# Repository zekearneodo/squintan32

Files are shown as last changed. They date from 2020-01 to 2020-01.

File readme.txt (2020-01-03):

Design files and helpers for a modular microdrive and headstage.

Authors: Ezequiel Arneodo, Corinna Lorenz, Richard Hahnloser.

Documentation in progress.

Deliverables:

 - rhd_2132_with_squiggle_logic: headstage module with intan chip, squiggle drive and controller/hall sensor for position monitoring. 
				 Molex connector for the probe.
	TODO: ready, produced with swisspcb (electric), mounted with Hybrid S.A
		
	main files:
	 - rhd_board.PrjPcb (altium project)

 - rev_1_mechanic: mechanical designs that go together with rhd_2132_with_squiggle_logic.
	TODO: ready, negotiating production with and with eth physics workshop (mechanical).

	main files:
	 - drive_rev_1.SLDASM

 - probe: pcb for assembly of the carbon fiber bundle probe. Connects to rhd_2132_with_squiggle with molex connector.
 	TODO: ready, negotiating production with swisspcb (electric)
	
	main files:
	 - probe_rev1.PrjPcb

 - altium_libraries: libraries of components with relevant 3d models (for connectors/microdrive).

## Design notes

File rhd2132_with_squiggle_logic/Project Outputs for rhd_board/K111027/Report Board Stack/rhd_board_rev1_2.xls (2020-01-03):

Board Stack Report
Stack Up |  |  |  | Layer Stack
Layer | intan | omnet-intan | intan-drive | Name | Material | Thickness | Constant
1 |  |  |  | Top Paste
2 |  |  |  | Fotolack | Solder Resist |  | 3.5
3 |  |  |  | Top Layer | Copper | 0.012mm
4 |  |  |  | Dielectric 1 | FR-4 | 0.022mm | 4.2
5 |  |  |  | Adhesive 1 |  | 0.025mm | 4.2
6 |  |  |  | GND | Copper | 0.012mm
7 |  |  |  | Adhesive 2 |  | 0.025mm | 4.2
8 |  |  |  | Dielectric 2 | FR-4 | 0.022mm | 4.2
9 |  |  |  | Bottom layer | Copper | 0.012mm
10 |  |  |  | Bottom Solder | Solder Resist |  | 3.5
11 |  |  |  | Bottom Paste
 | Height : 0.130mm | Height : 0.118mm | Height : 0.106mm

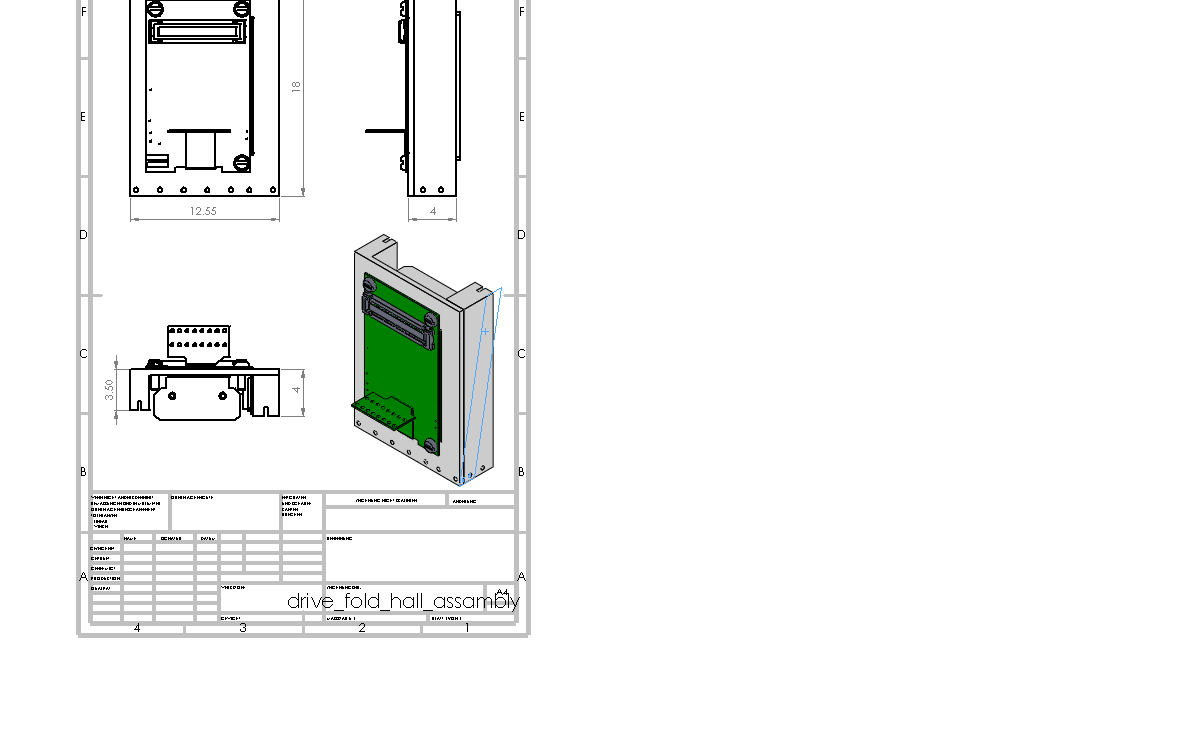
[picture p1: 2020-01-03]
rev_1_mechanic/drive_fold_hall_assambly.PNG

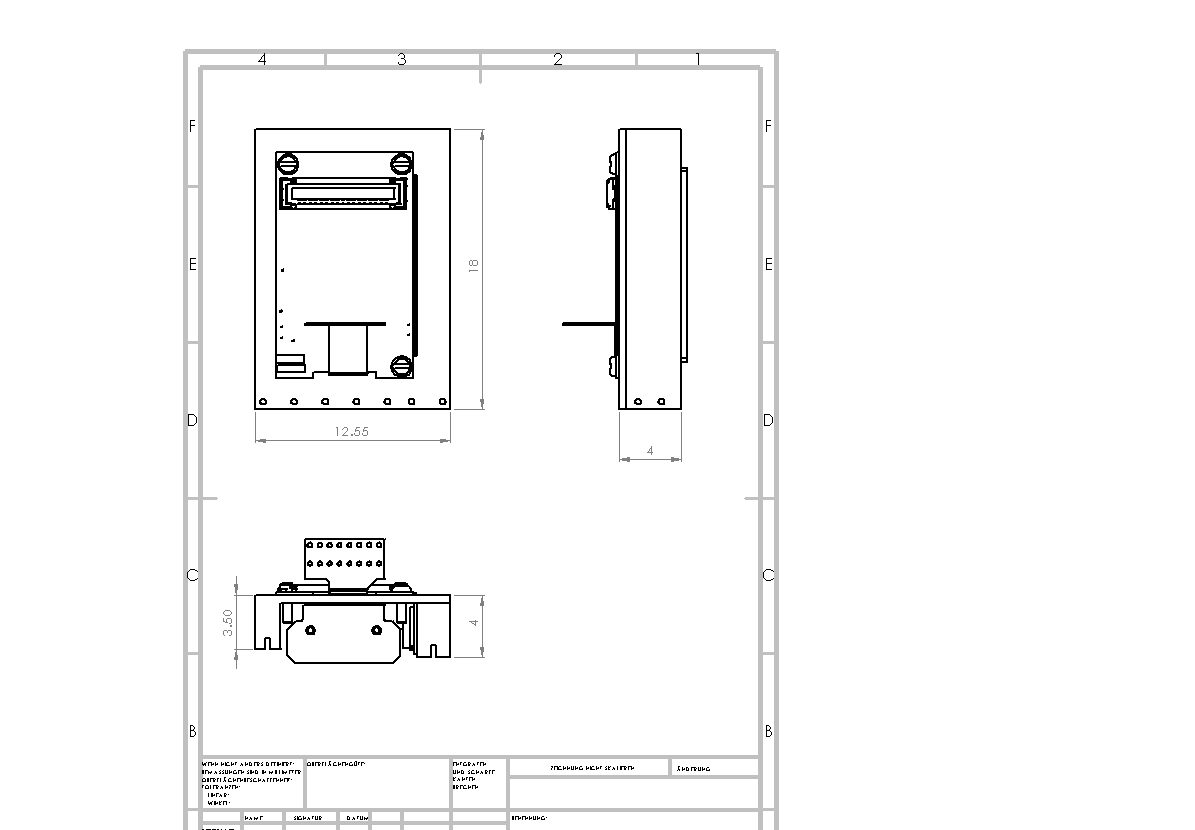
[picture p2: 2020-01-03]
rev_1_mechanic/drawings/drive_fold_hall_assambly.PNG

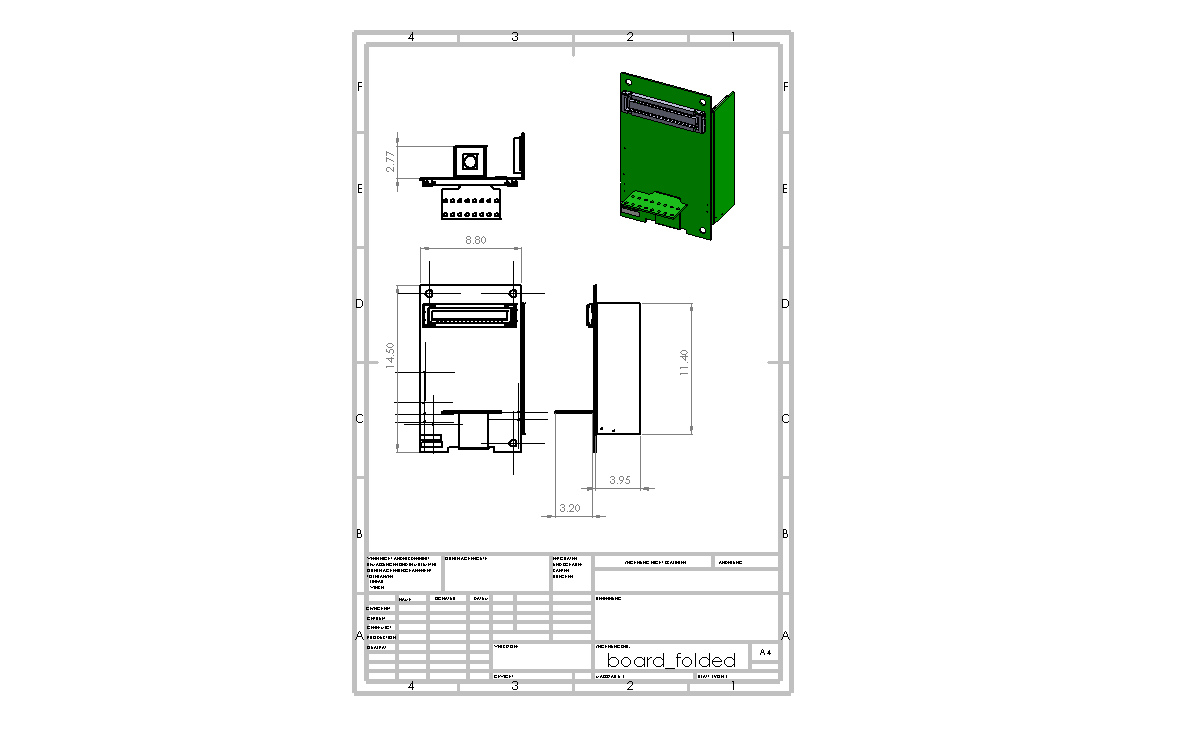
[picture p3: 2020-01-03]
rhd2132_with_squiggle_logic/output_3d_model/board_folded.PNG

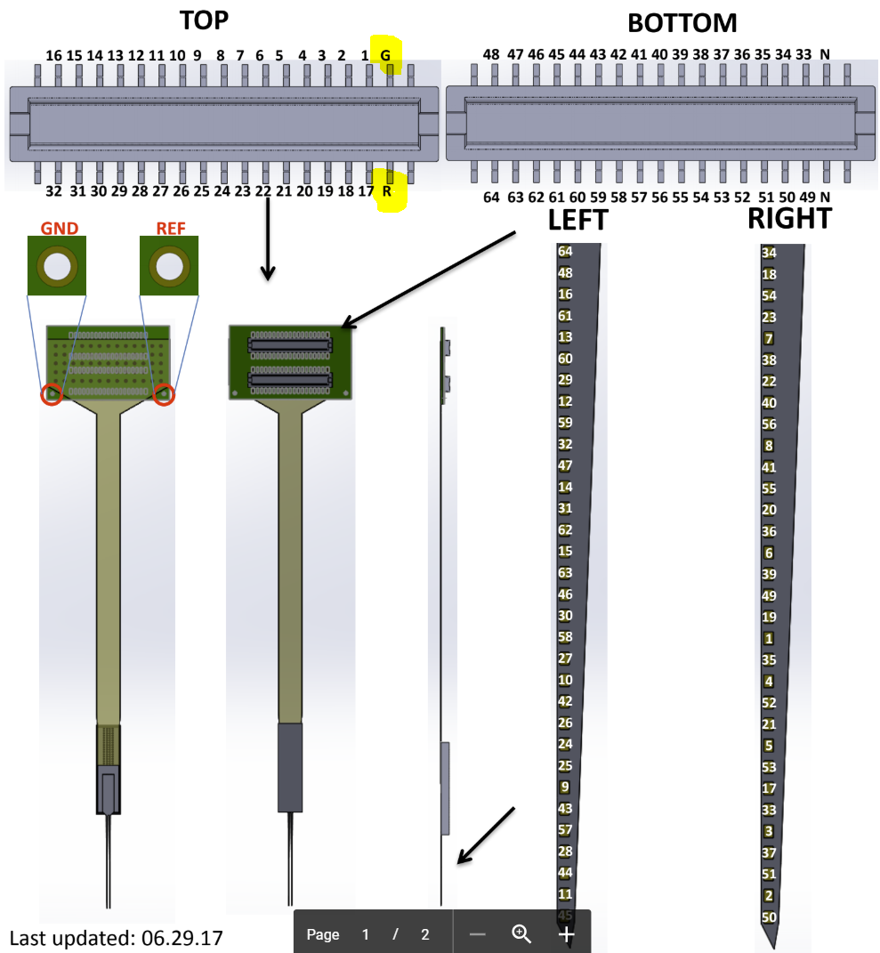
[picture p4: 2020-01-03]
datasheets/cambridge_neuro_64_map.png

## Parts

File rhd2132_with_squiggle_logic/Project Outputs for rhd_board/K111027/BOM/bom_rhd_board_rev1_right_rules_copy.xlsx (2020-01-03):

Comment | Description | Designator | Footprint | LibRef | Manufacturer 1 | Manufacturer Part Number 1 | Quantity | Supplier 1 | Supplier Part Number 1 | assembly comments
PCB Test Point |  | AI, AI2, AI3, DO, gnd-u, GND, REF, vcc-u, VDD | TESTPOINT_SMALL | TESTPOINT_SMALL |  |  | 9
100nF |  | C1 | 0402-SMALL | C_0402 | Taiyo Yuden (https://octopart-clicks.com/click/altium?sku=963-TMK063ABJ104KP-F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) | TMK063ABJ104KP-F (https://octopart-clicks.com/click/altium?sku=963-TMK063ABJ104KP-F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) | 1 | Mouser | 963-TMK063ABJ104KP-F (https://octopart-clicks.com/click/altium?sku=963-TMK063ABJ104KP-F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)
10nF |  | C2 | 0402-SMALL | C_0402 | Taiyo Yuden (https://octopart-clicks.com/click/altium?sku=963-TMK063BJ103KP-F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) | TMK063BJ103KP-F (https://octopart-clicks.com/click/altium?sku=963-TMK063BJ103KP-F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) | 1 | Mouser | 963-TMK063BJ103KP-F (https://octopart-clicks.com/click/altium?sku=963-TMK063BJ103KP-F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)
470n | Capacitor | C7, C9, C10 | CAPC0603X03L | Cap-0201 | Taiyo Yuden (https://octopart-clicks.com/click/altium?sku=963-AMK063BJ474MP-F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) | AMK063BJ474MP-F (https://octopart-clicks.com/click/altium?sku=963-AMK063BJ474MP-F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) | 3 | Mouser | 963-AMK063BJ474MP-F (https://octopart-clicks.com/click/altium?sku=963-AMK063BJ474MP-F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)
10u | Capacitor | C8, C11 | CAPC1608X09L | Cap-0603 | Panasonic (https://octopart-clicks.com/click/altium?sku=667-ECJ-1VB0J106M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) | ECJ-1VB0J106M (https://octopart-clicks.com/click/altium?sku=667-ECJ-1VB0J106M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) | 2 | Mouser | 667-ECJ-1VB0J106M (https://octopart-clicks.com/click/altium?sku=667-ECJ-1VB0J106M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)
NSD-2101 |  | D0 | BGA16C40P4X4_175X175X63 | NSD-2101 | austriamicrosystems | nsd-2101CSP | 1
NSE-5310_FC |  | D1 | NSE-5310_FC | NSE-5310_FC | austriamicrosystems | 179910002 | 1
sql-rv-1.8-6-12 | Squiggle motor | piezo-drive | sql-rv-1.8-6-12 | sql-rv-1.8-6-12 |  |  | 1 |  |  | will be assembled later in the lab
0 |  | R0 | 0201-SMALL | R_0402 | Panasonic (https://octopart-clicks.com/click/altium?sku=667-ERJ-1GN0R00C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) | ERJ-1GN0R00C (https://octopart-clicks.com/click/altium?sku=667-ERJ-1GN0R00C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) | 1 | Mouser | 667-ERJ-1GN0R00C (https://octopart-clicks.com/click/altium?sku=667-ERJ-1GN0R00C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)
100 |  | R1, R2, R3 | 0201-SMALL | R_0402 | Rohm (https://octopart-clicks.com/click/altium?sku=755-UCR006YVPFLR100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) | UCR006YVPFLR100 (https://octopart-clicks.com/click/altium?sku=755-UCR006YVPFLR100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) | 3 | Mouser | 755-UCR006YVPFLR100 (https://octopart-clicks.com/click/altium?sku=755-UCR006YVPFLR100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)
Omnetics_PZN-16-DD |  | S0 | OMNETICS_PZN-16-DD | Omnetics_PZN-16-DD |  |  | 1 |  |  | will be assembled later in the lab
Molex 3.5mm Pitch Slimstack 34 pin connector |  | S1 | MOLEX_504618-3412 | MOLEX_504618-3412 | Molex (https://octopart-clicks.com/click/altium?sku=538-504618-3410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) | 5046183410 (https://octopart-clicks.com/click/altium?sku=538-504618-3410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) | 1 | Mouser | 538-504618-3410 (https://octopart-clicks.com/click/altium?sku=538-504618-3410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)
Intan Technologies RHD2132 chip |  | U0 | RHD2000_56PIN_COB | RHD2132_COB | Intan Technologies | #P8004 | 1 |  |  | COB assembly

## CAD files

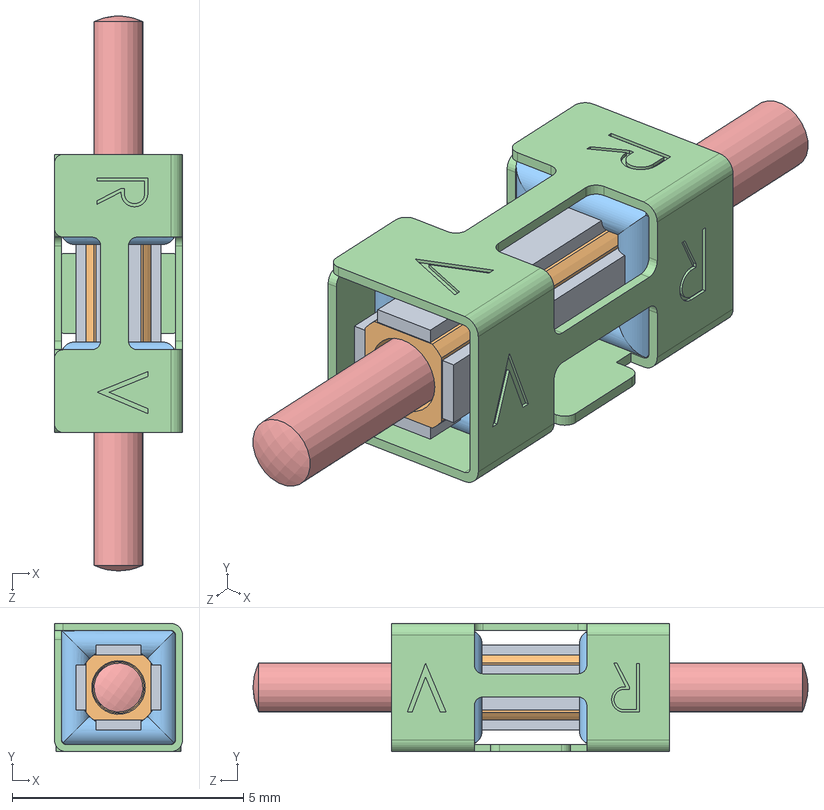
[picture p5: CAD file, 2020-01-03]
altium_libraries/Microdrive_Drive/3d_footprints/SQL-RV-1.8-6-12_nocable.STEP.SLDASM
2.77 x 2.77 x 12.0 mm
01594-0-0000_drawing view
02559-0-0000_WRAPPED x 2
02915-0-0000_Correct Wrap
01593-0-1012_MODEL

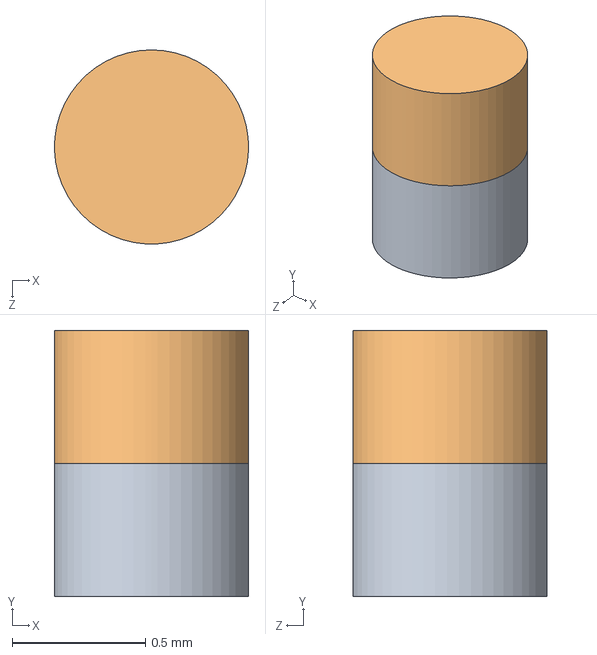
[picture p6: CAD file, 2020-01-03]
rev_1_mechanic/AssemMagnet.SLDASM
0.73 x 1.00 x 0.73 mm
Magnet_S
Magnet_N

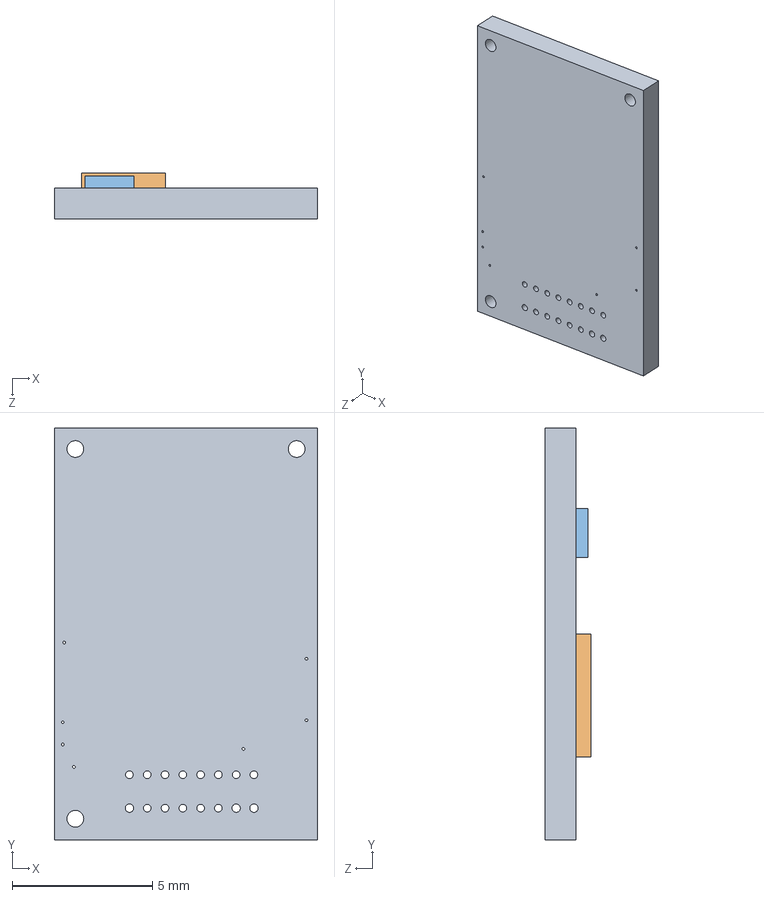
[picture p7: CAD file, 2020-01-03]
rhd2132_with_squiggle_logic/mechanical/board.SLDASM
9.40 x 14.7 x 1.63 mm
Boardtv
Extruded_1_4

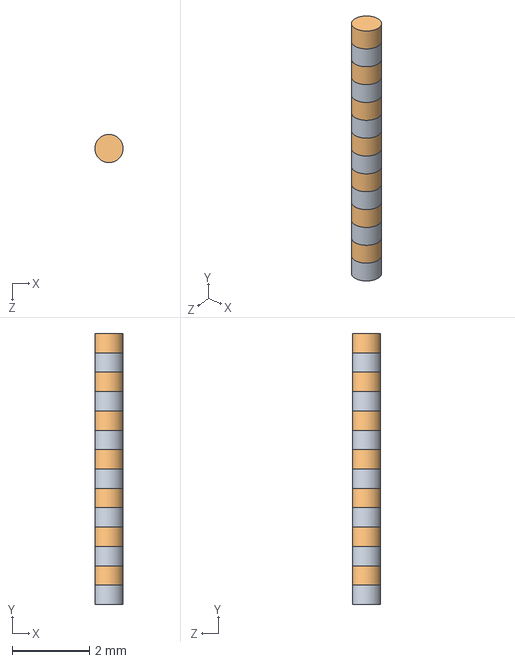
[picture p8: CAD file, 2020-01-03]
rev_1_mechanic/AssemMagnet7.SLDASM
0.73 x 7.00 x 0.73 mm
Magnet_S x 7
Magnet_N x 7

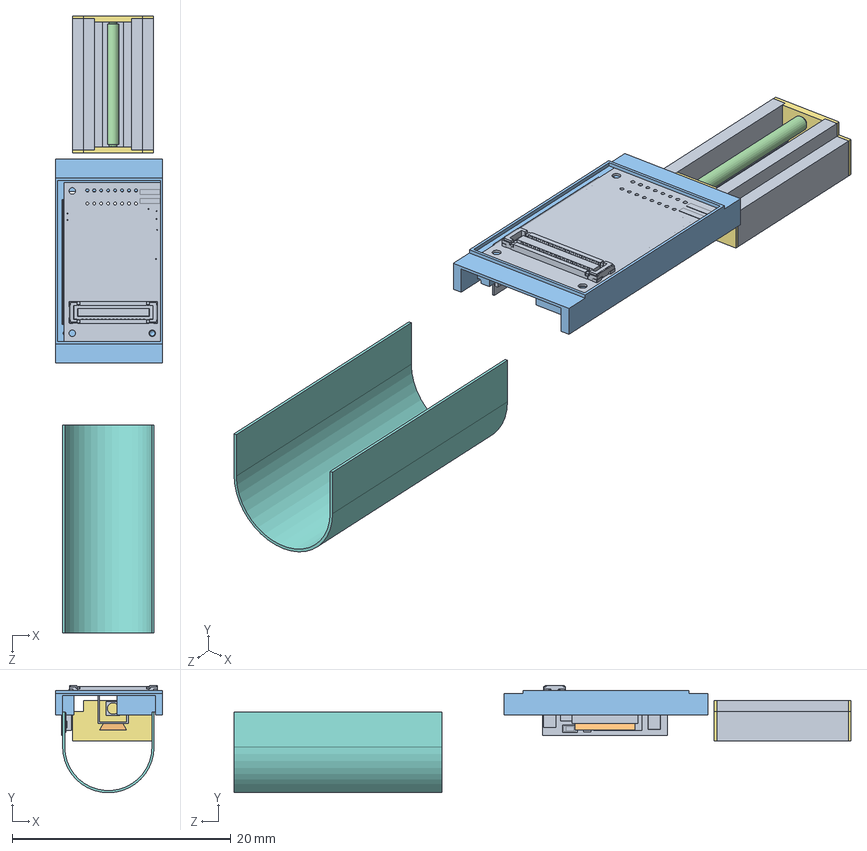
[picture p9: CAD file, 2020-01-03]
rev_1_mechanic/drive_rev_1_assembyl.SLDASM
9.82 x 9.82 x 56.4 mm
shuttle_female_slider
derived_slider_female
frame
shaft
shuttle_cap x 2
rhd_board_rev1_right_ruless_375hallpy

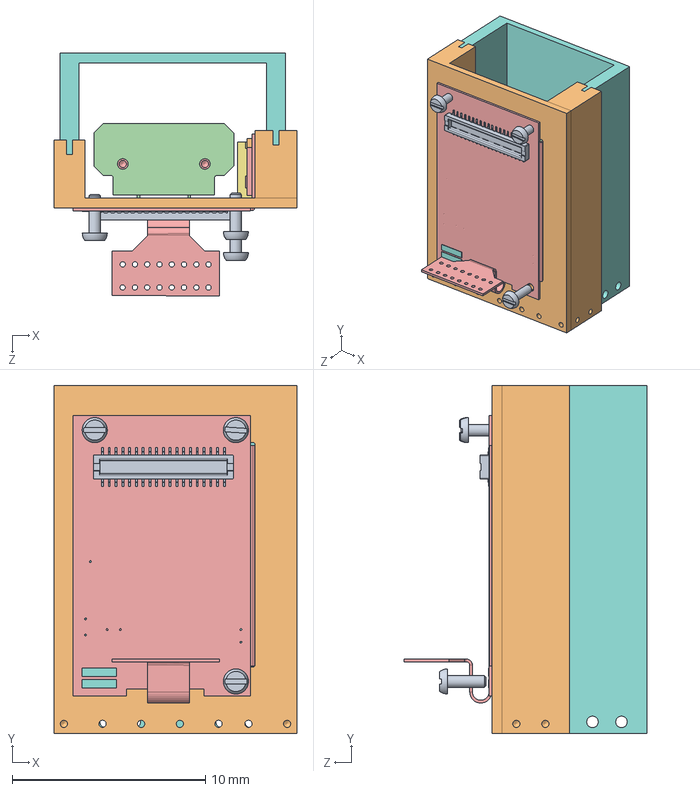
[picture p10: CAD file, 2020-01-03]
rev_1_mechanic/drive_fold_hall_assambly.SLDASM
12.5 x 18.0 x 12.5 mm
derived_slider_female
frame_folded_hall
shaft
shuttle_cap x 2
shuttle_female_slider
Magnet_S x 7
Magnet_N x 7
60unm_screw x 3
Extruded x 2
Extruded-1
Extruded-2
Extruded-3
Extruded-4
Extruded-5
Extruded-6 x 2
Extruded-7 x 2
Extruded-8 x 2
Extruded-9 x 2
Extruded-10 x 2
Extruded-11 x 2
Extruded-12 x 2
Extruded-14 x 2
Extruded-15 x 2
Extruded-16
Extruded-17
Extruded-18
Extruded-19
Extruded-20
Extruded-21
Extruded-23
Extruded-24 x 2
5046223410-Part-2
Extruded-25 x 4
sql-rv-1.8-6-12_nc
sql-rv-1.8-6-12_nc-1
Board

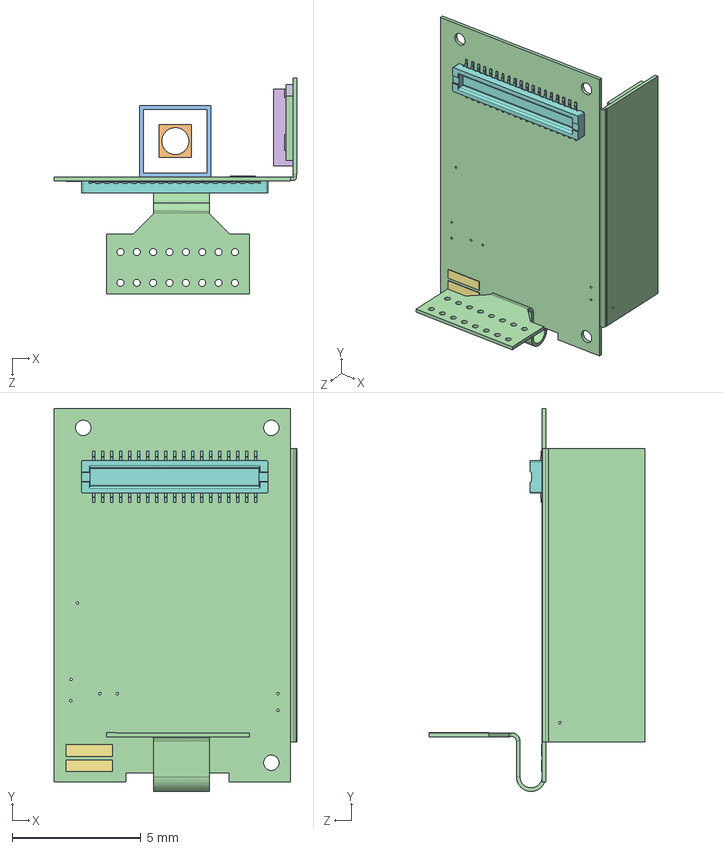
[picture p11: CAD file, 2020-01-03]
rhd2132_with_squiggle_logic/output_3d_model/rhd2132_board_rev1_2_x_t.SLDASM
9.43 x 14.9 x 8.38 mm
Extruded x 2
Extruded-1
Extruded-2
Extruded-3
Extruded-4
Extruded-5
Extruded-6 x 2
Extruded-7 x 2
Extruded-8 x 2
Extruded-9 x 2
Extruded-10 x 2
Extruded-11 x 2
Extruded-12 x 2
Extruded-14 x 2
Extruded-15 x 2
Extruded-16
Extruded-17
Extruded-18
Extruded-19
Extruded-20
Extruded-21
Extruded-23
Extruded-24 x 2
5046223410-Part-2
Extruded-25 x 4
sql-rv-1.8-6-12_nc
sql-rv-1.8-6-12_nc-1
Board

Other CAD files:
rhd2132_with_squiggle_logic/output_3d_model/C8.sldasm
rhd2132_with_squiggle_logic/output_3d_model/D0.sldasm
rhd2132_with_squiggle_logic/output_3d_model/rhd2132_with_squiggle_logic.SLDASM
rhd2132_with_squiggle_logic/output_3d_model/C7.sldasm
rhd2132_with_squiggle_logic/output_3d_model/C9.sldasm
rhd2132_with_squiggle_logic/output_3d_model/C11.sldasm
rhd2132_with_squiggle_logic/output_3d_model/piezo-drive-subassembly-1.sldasm
rhd2132_with_squiggle_logic/output_3d_model/c1.SLDASM
rhd2132_with_squiggle_logic/output_3d_model/piezo-drive.sldasm
rhd2132_with_squiggle_logic/output_3d_model/S1.sldasm
rhd2132_with_squiggle_logic/output_3d_model/PS+.sldasm
altium_libraries/Microdrive_Drive/3d_footprints/5046183410.stp
altium_libraries/Microdrive_Drive/3d_footprints/5046223410.stp
altium_libraries/Microdrive_Drive/3d_footprints/A79624-001.STEP
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

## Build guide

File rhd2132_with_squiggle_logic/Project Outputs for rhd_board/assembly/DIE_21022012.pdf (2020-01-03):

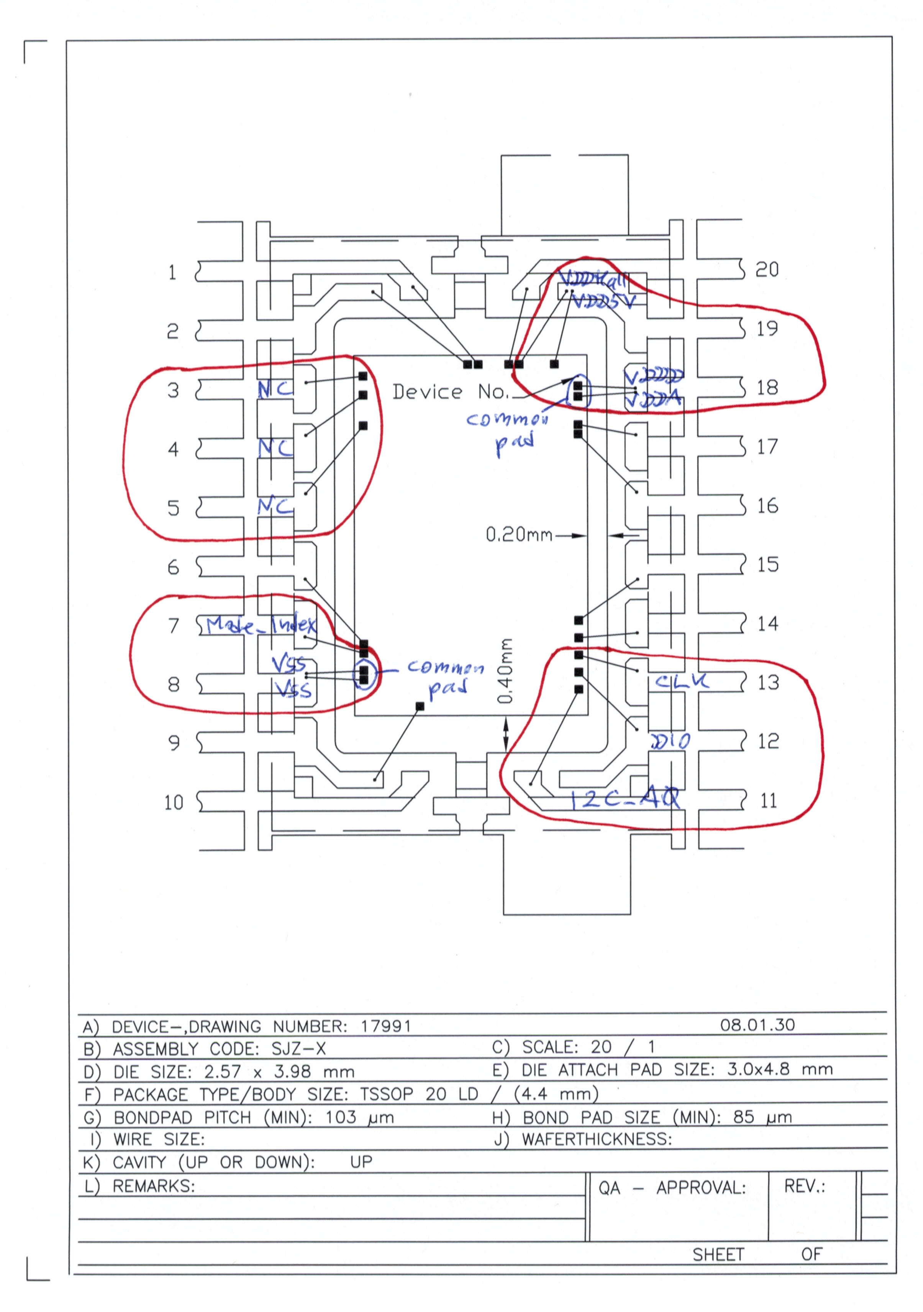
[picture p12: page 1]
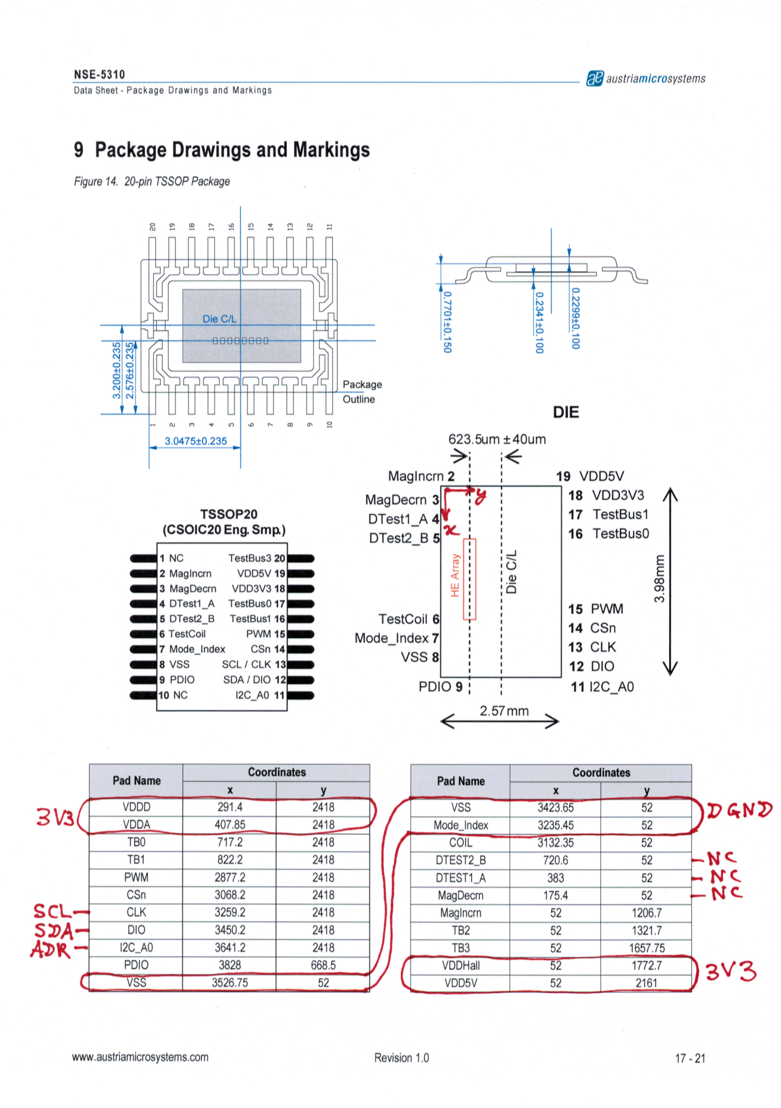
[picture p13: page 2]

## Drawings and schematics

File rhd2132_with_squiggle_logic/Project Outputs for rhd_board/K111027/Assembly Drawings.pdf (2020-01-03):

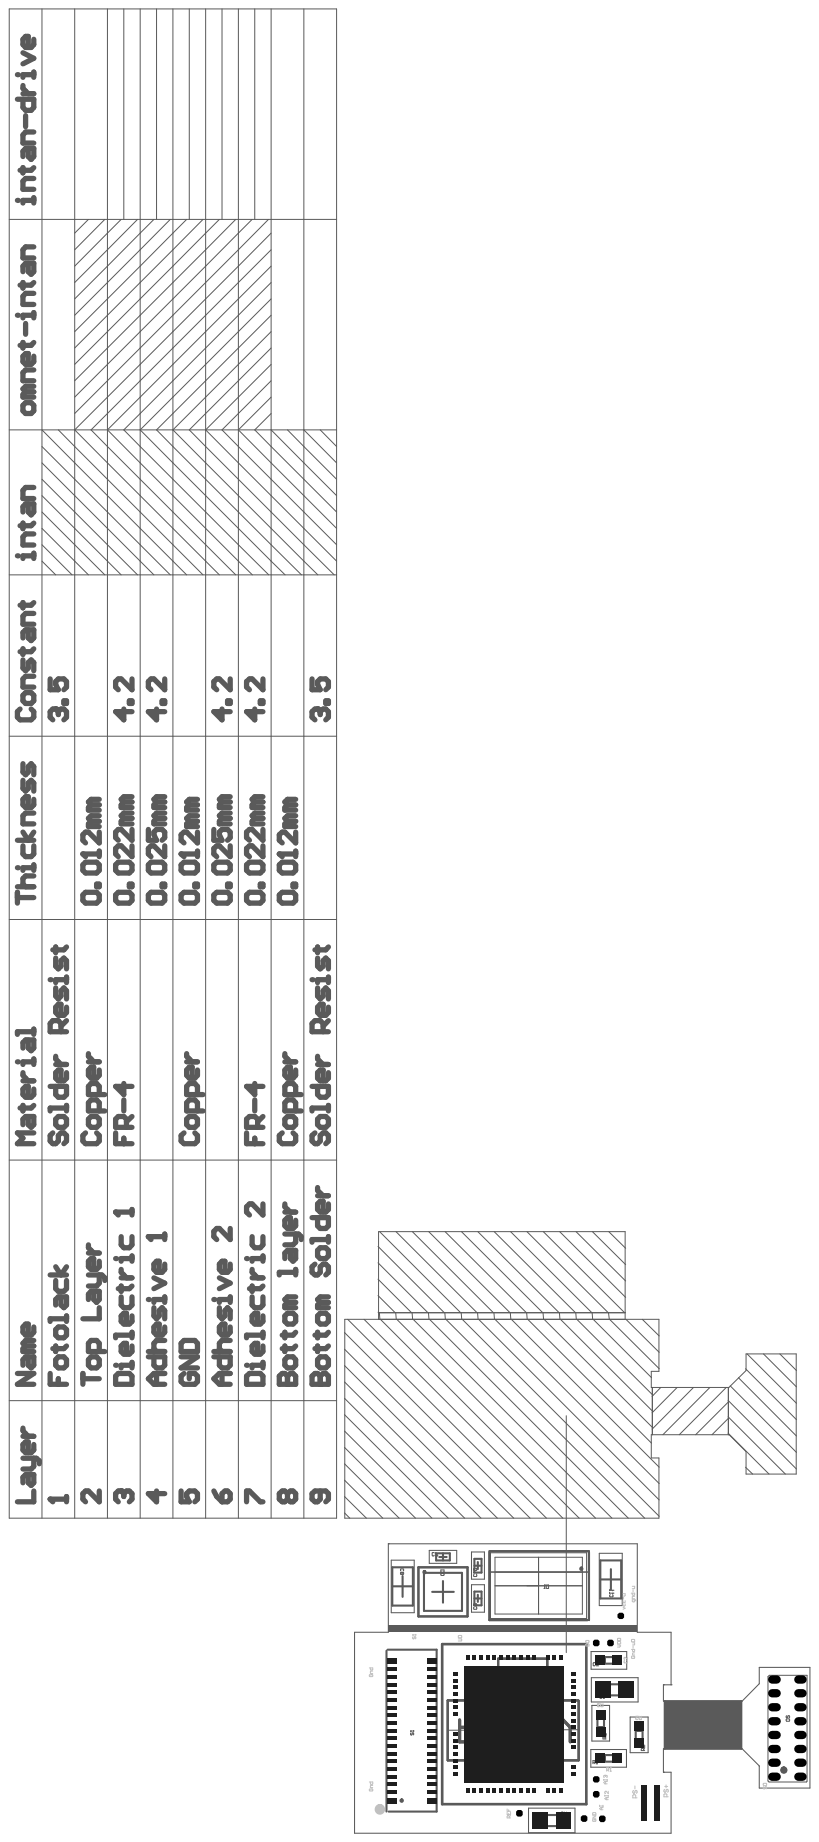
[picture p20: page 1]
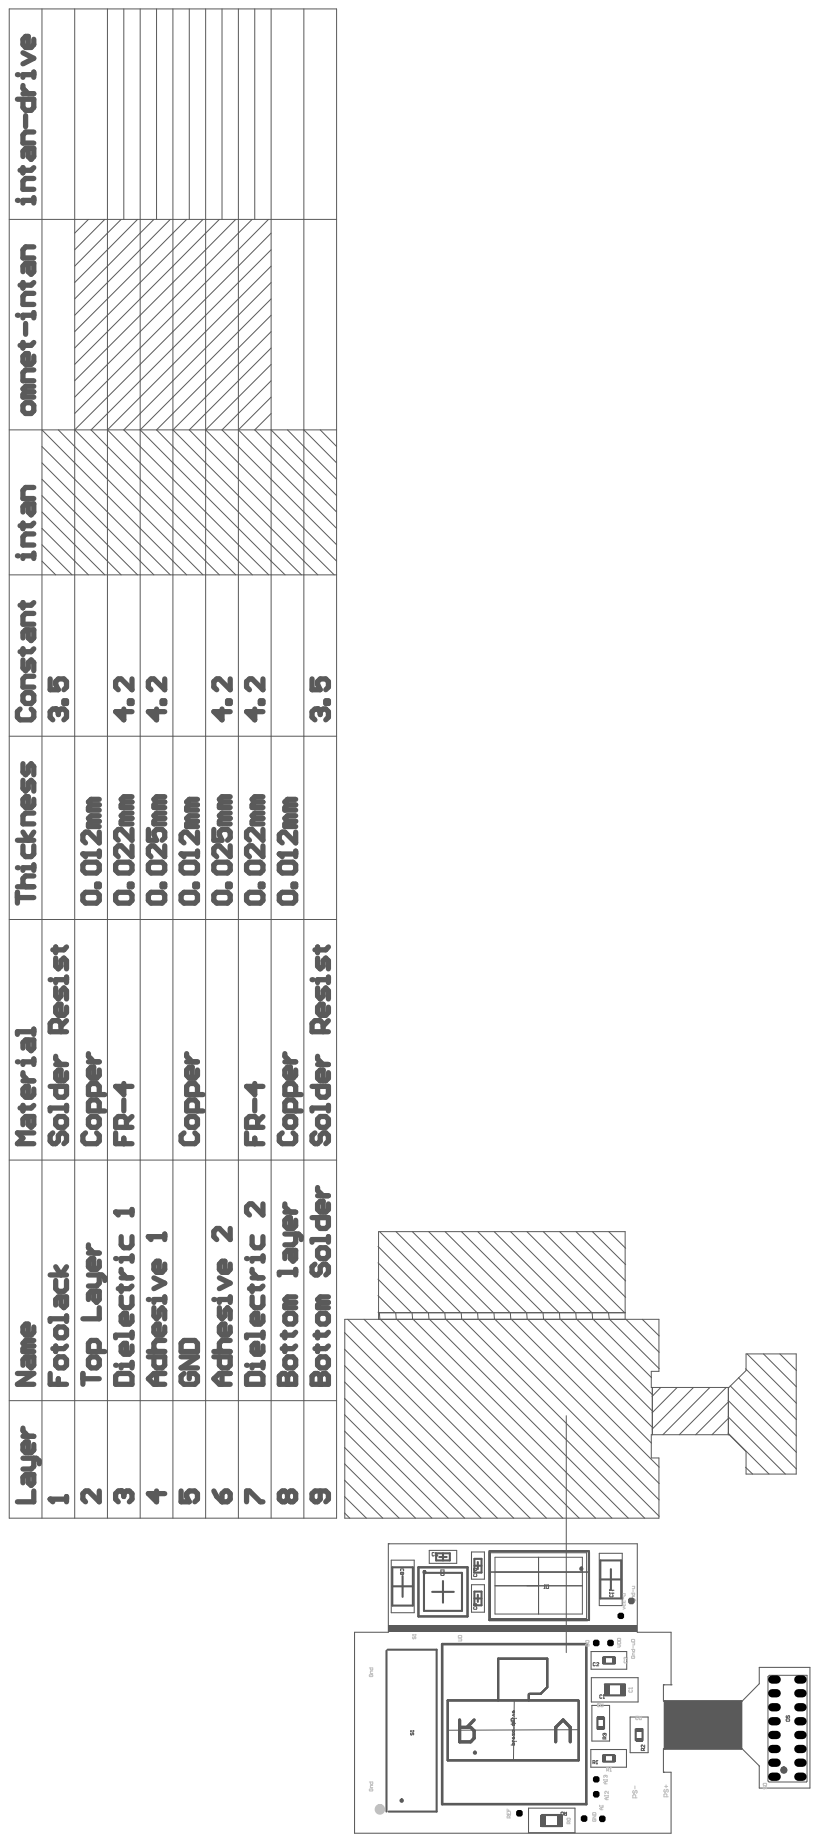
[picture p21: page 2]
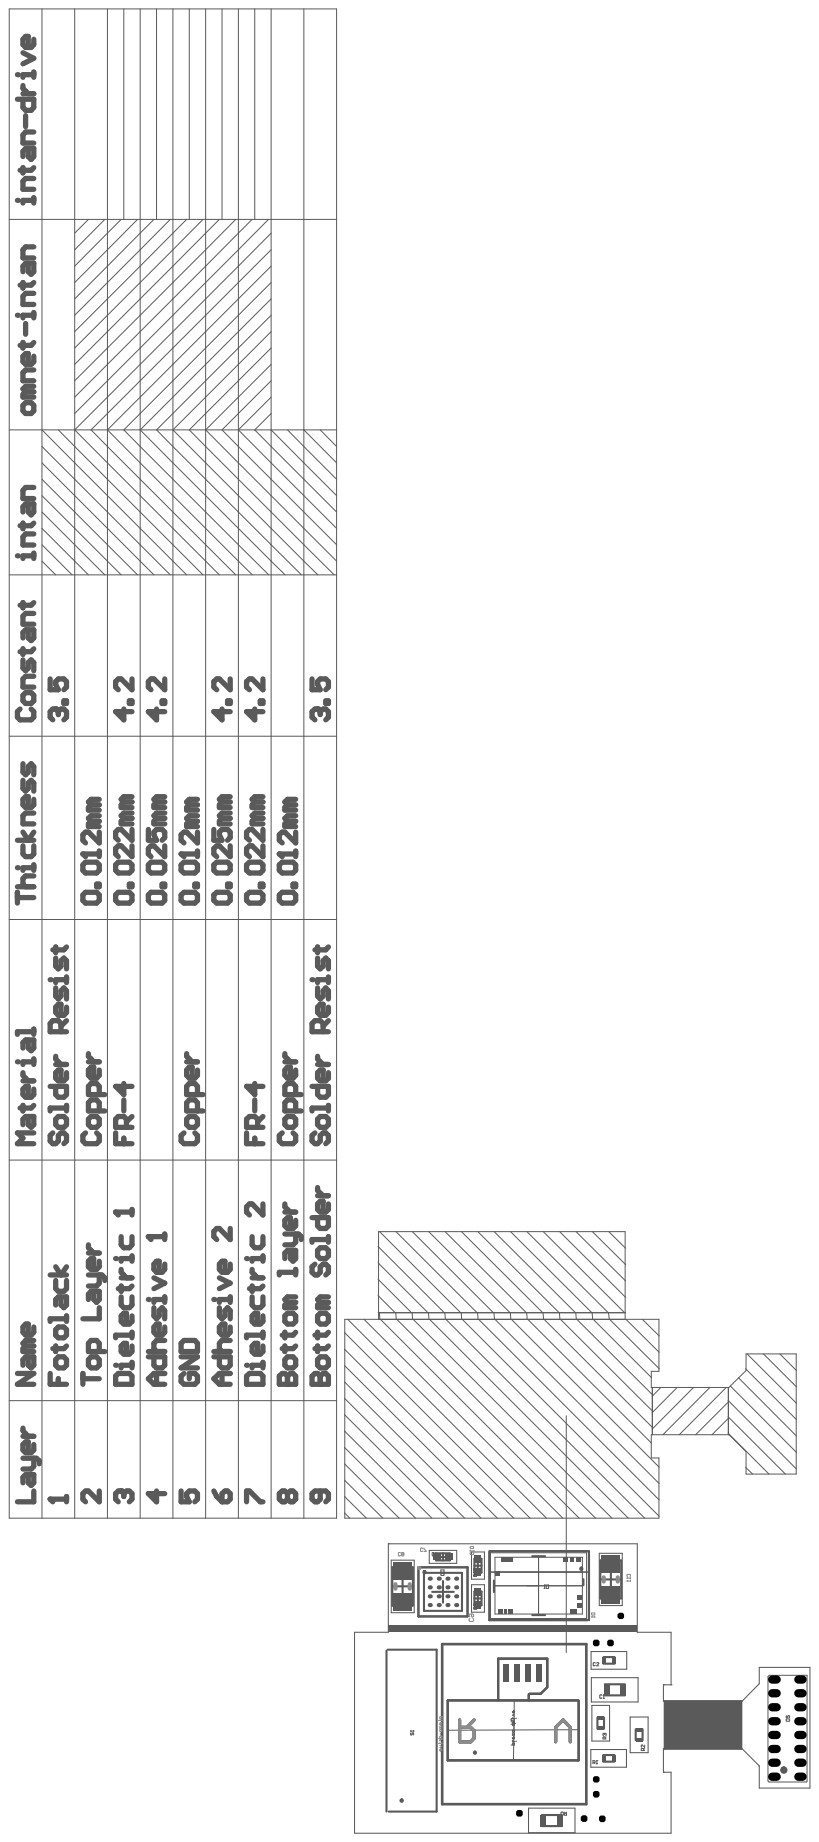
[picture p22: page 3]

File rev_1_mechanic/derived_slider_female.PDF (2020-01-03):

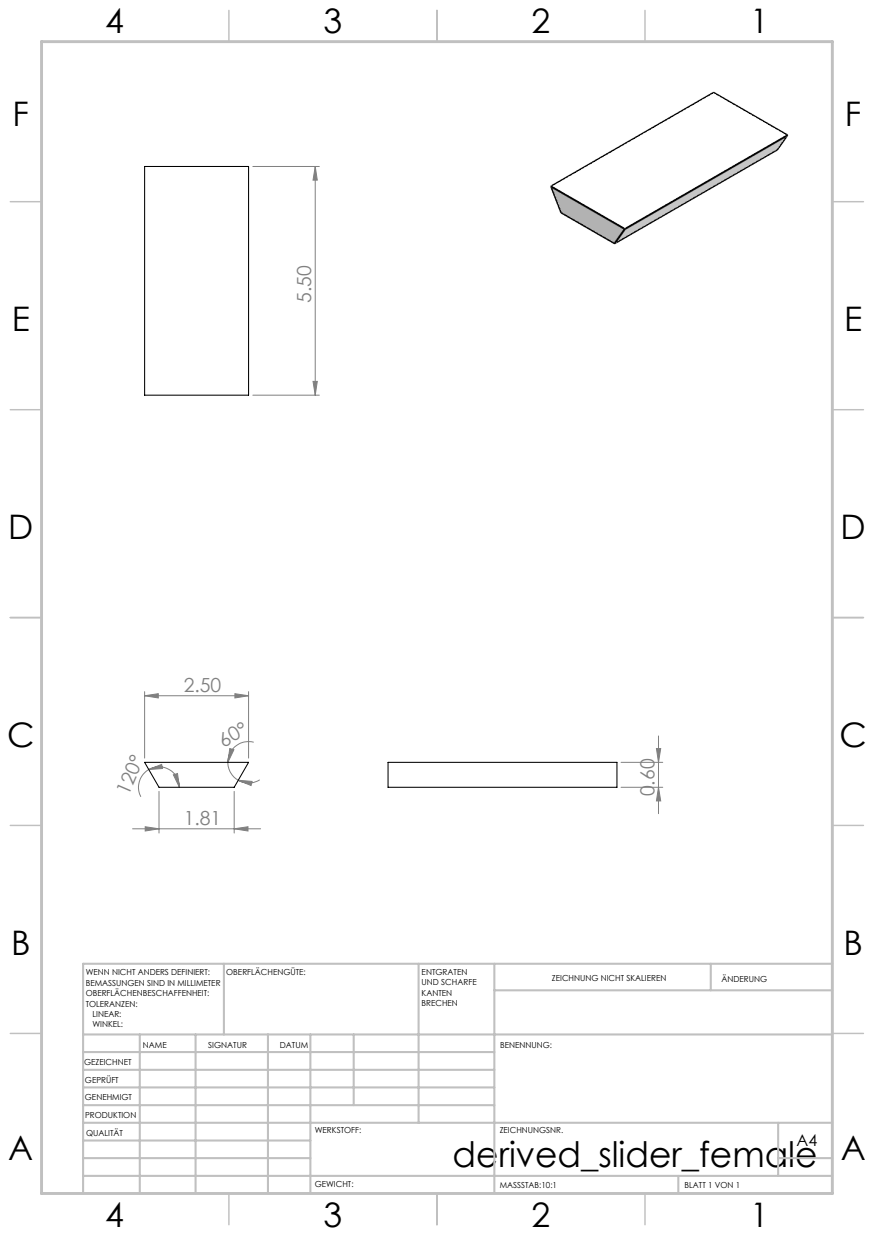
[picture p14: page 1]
MASSSTAB:10:1; BLATT 1 VON 1; ZEICHNUNG NICHT SKALIEREN; ÄNDERUNG; UND SCHARFE; WENN NICHT ANDERS DEFINIERT:; OBERFLÄCHENGÜTE:

BEMASSUNGEN SIND IN MILLIMETER
OBERFLÄCHENBESCHAFFENHEIT:
TOLERANZEN:
LINEAR:
WINKEL:

NAME | SIGNATUR | DATUM | | | | BENENNUNG:
QUALITÄT | | | | WERKSTOFF: derived_slider_female GEWICHT: | ZEICHNUNGSNR. | A4

GEZEICHNET
GEPRÜFT
GENEHMIGT
PRODUKTION

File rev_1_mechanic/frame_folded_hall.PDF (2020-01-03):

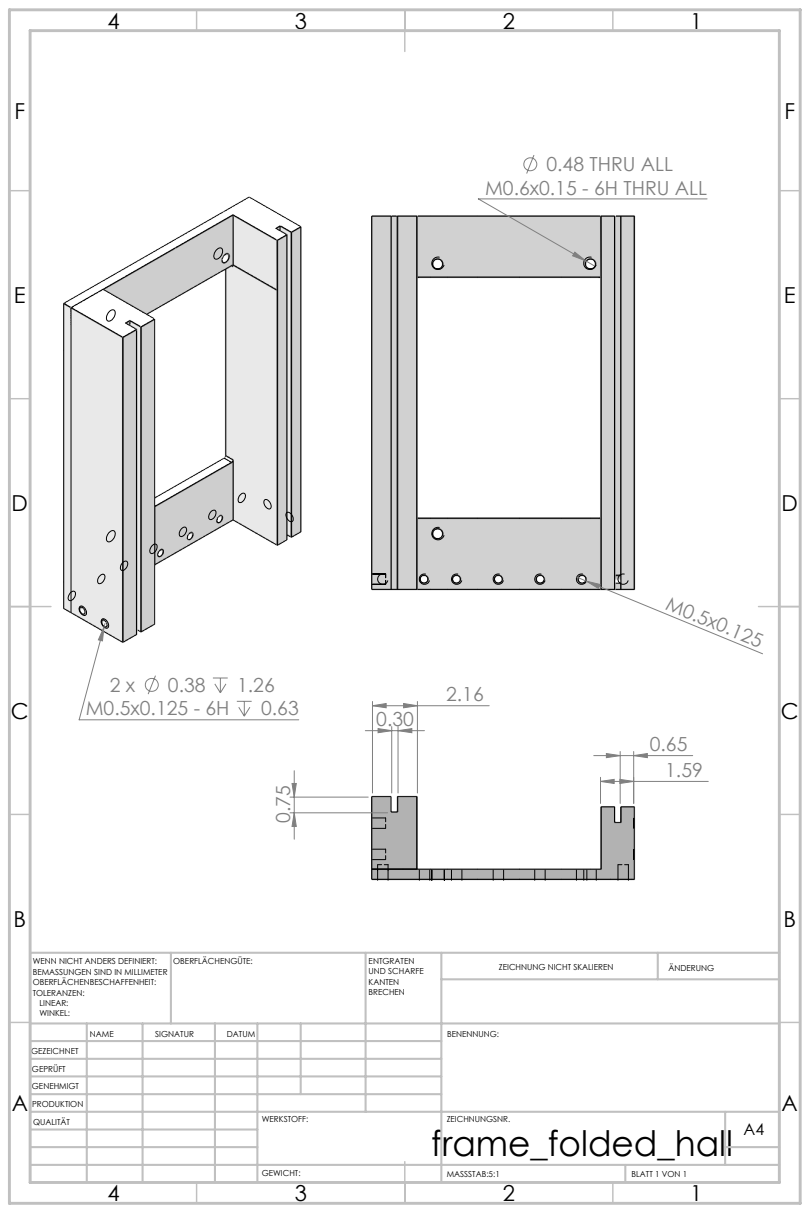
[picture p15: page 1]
0.48 THRU ALL M0.6x0.15 - 6H THRU ALL; MASSSTAB:5:1; BLATT 1 VON 1; ZEICHNUNG NICHT SKALIEREN; ÄNDERUNG; UND SCHARFE; WENN NICHT ANDERS DEFINIERT:; OBERFLÄCHENGÜTE:

BEMASSUNGEN SIND IN MILLIMETER
OBERFLÄCHENBESCHAFFENHEIT:
TOLERANZEN:
LINEAR:
WINKEL:

NAME | SIGNATUR | DATUM | | | | BENENNUNG:
QUALITÄT | | | | WERKSTOFF: frame_folded_hall GEWICHT: | ZEICHNUNGSNR. | A4

GEZEICHNET
GEPRÜFT
GENEHMIGT
PRODUKTION

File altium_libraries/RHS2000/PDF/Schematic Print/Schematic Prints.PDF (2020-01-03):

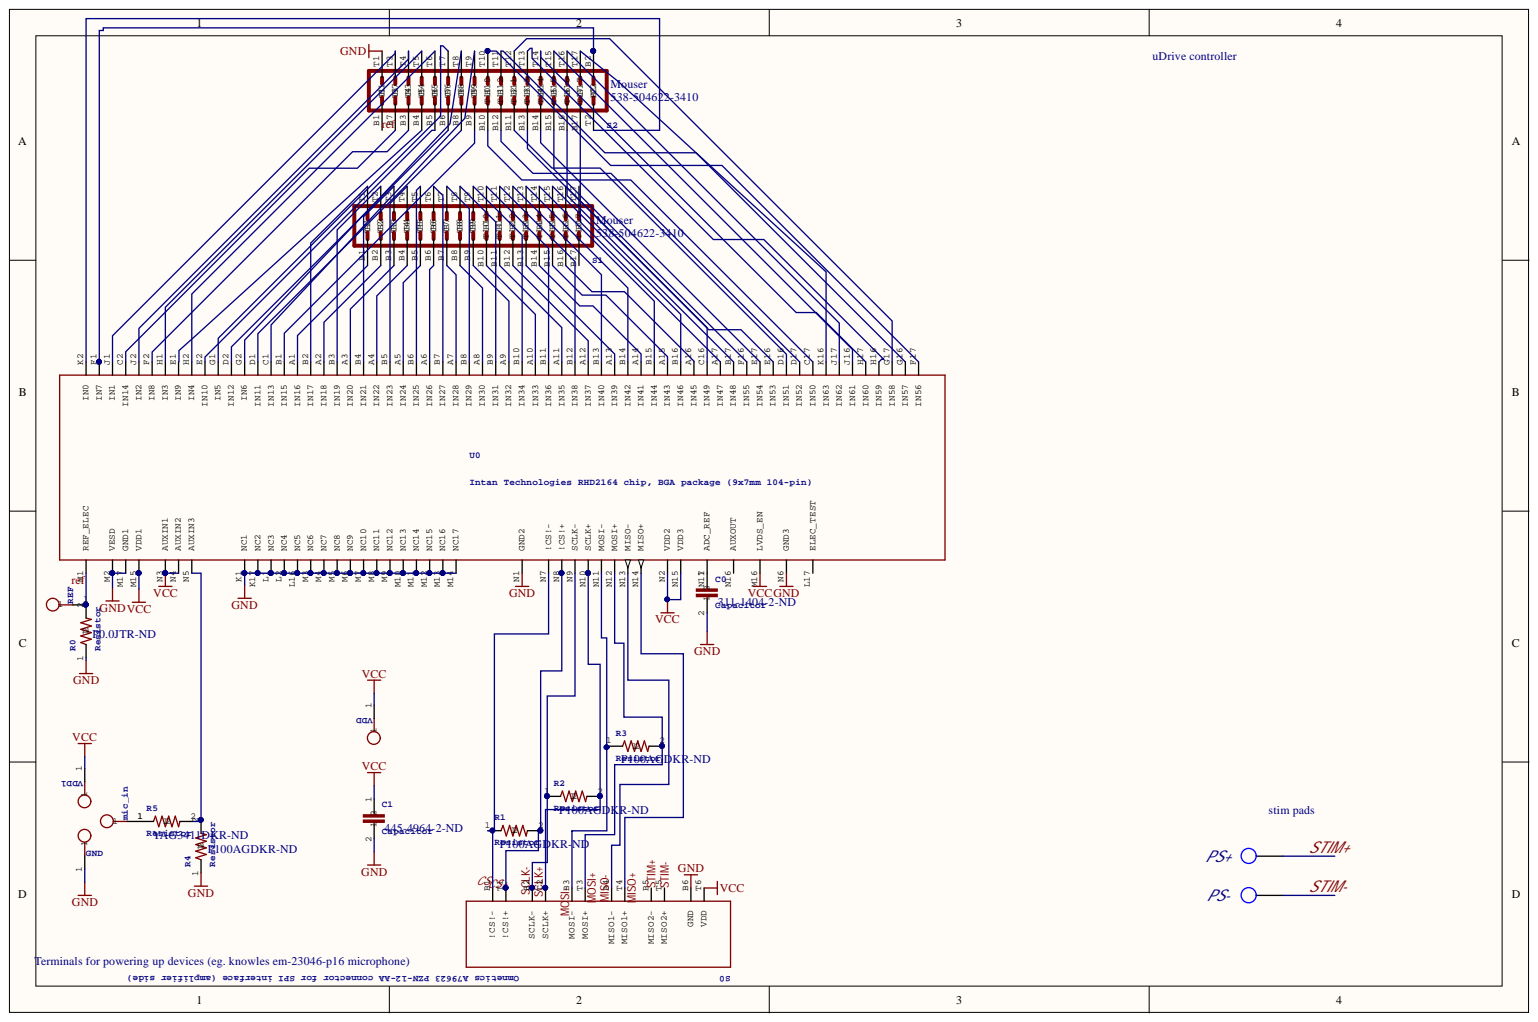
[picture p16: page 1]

Intan Technologies RHD2164 chip, BGA package (9x7mm 104-pin)

Terminals for powering up devices (eg. knowles em-23046-p16 microphone)

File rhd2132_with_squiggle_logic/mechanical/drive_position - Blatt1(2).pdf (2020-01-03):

A | 5.10 | A

B B

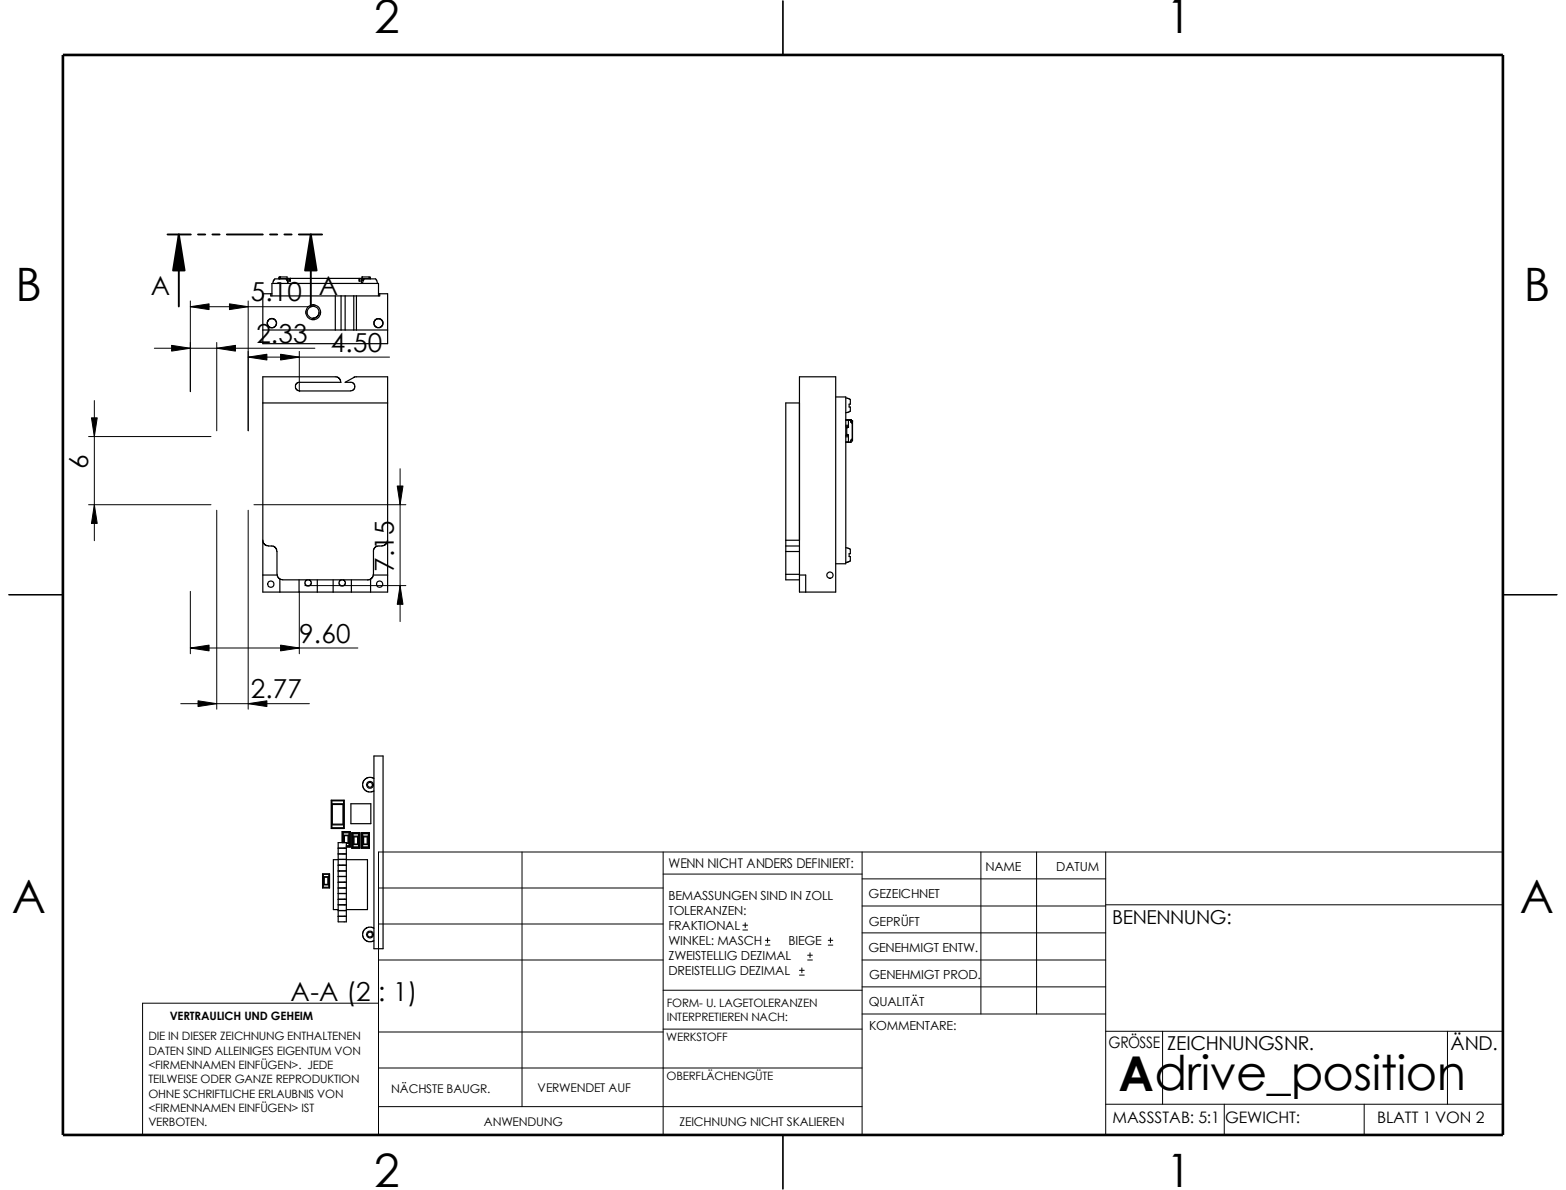
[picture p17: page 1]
KOMMENTARE:

WENN NICHT ANDERS DEFINIERT: | | NAME | DATUM

BEMASSUNGEN SIND IN ZOLL TOLERANZEN: FRAKTIONAL WINKEL: MASCH BIEGE ZWEISTELLIG DEZIMAL DREISTELLIG DEZIMAL | GEZEICHNET

GEPRÜFT | | | BENENNUNG:

GENEHMIGT ENTW.

GENEHMIGT PROD.

FORM- U. LAGETOLERANZEN INTERPRETIEREN NACH: | QUALITÄT

VERTRAULICH UND GEHEIM
DIE IN DIESER ZEICHNUNG ENTHALTENEN
DATEN SIND ALLEINIGES EIGENTUM VON
<FIRMENNAMEN EINFÜGEN>. JEDE
TEILWEISE ODER GANZE REPRODUKTION
OHNE SCHRIFTLICHE ERLAUBNIS VON
<FIRMENNAMEN EINFÜGEN> IST
VERBOTEN.

WERKSTOFF | | GRÖSSE A drive_position | ZEICHNUNGSNR. | ÄND.

NÄCHSTE BAUGR. | VERWENDET AUF | OBERFLÄCHENGÜTE

ANWENDUNG | ZEICHNUNG NICHT SKALIEREN | | MASSSTAB: 5:1 | GEWICHT: | BLATT 1 VON 2

D D

C C

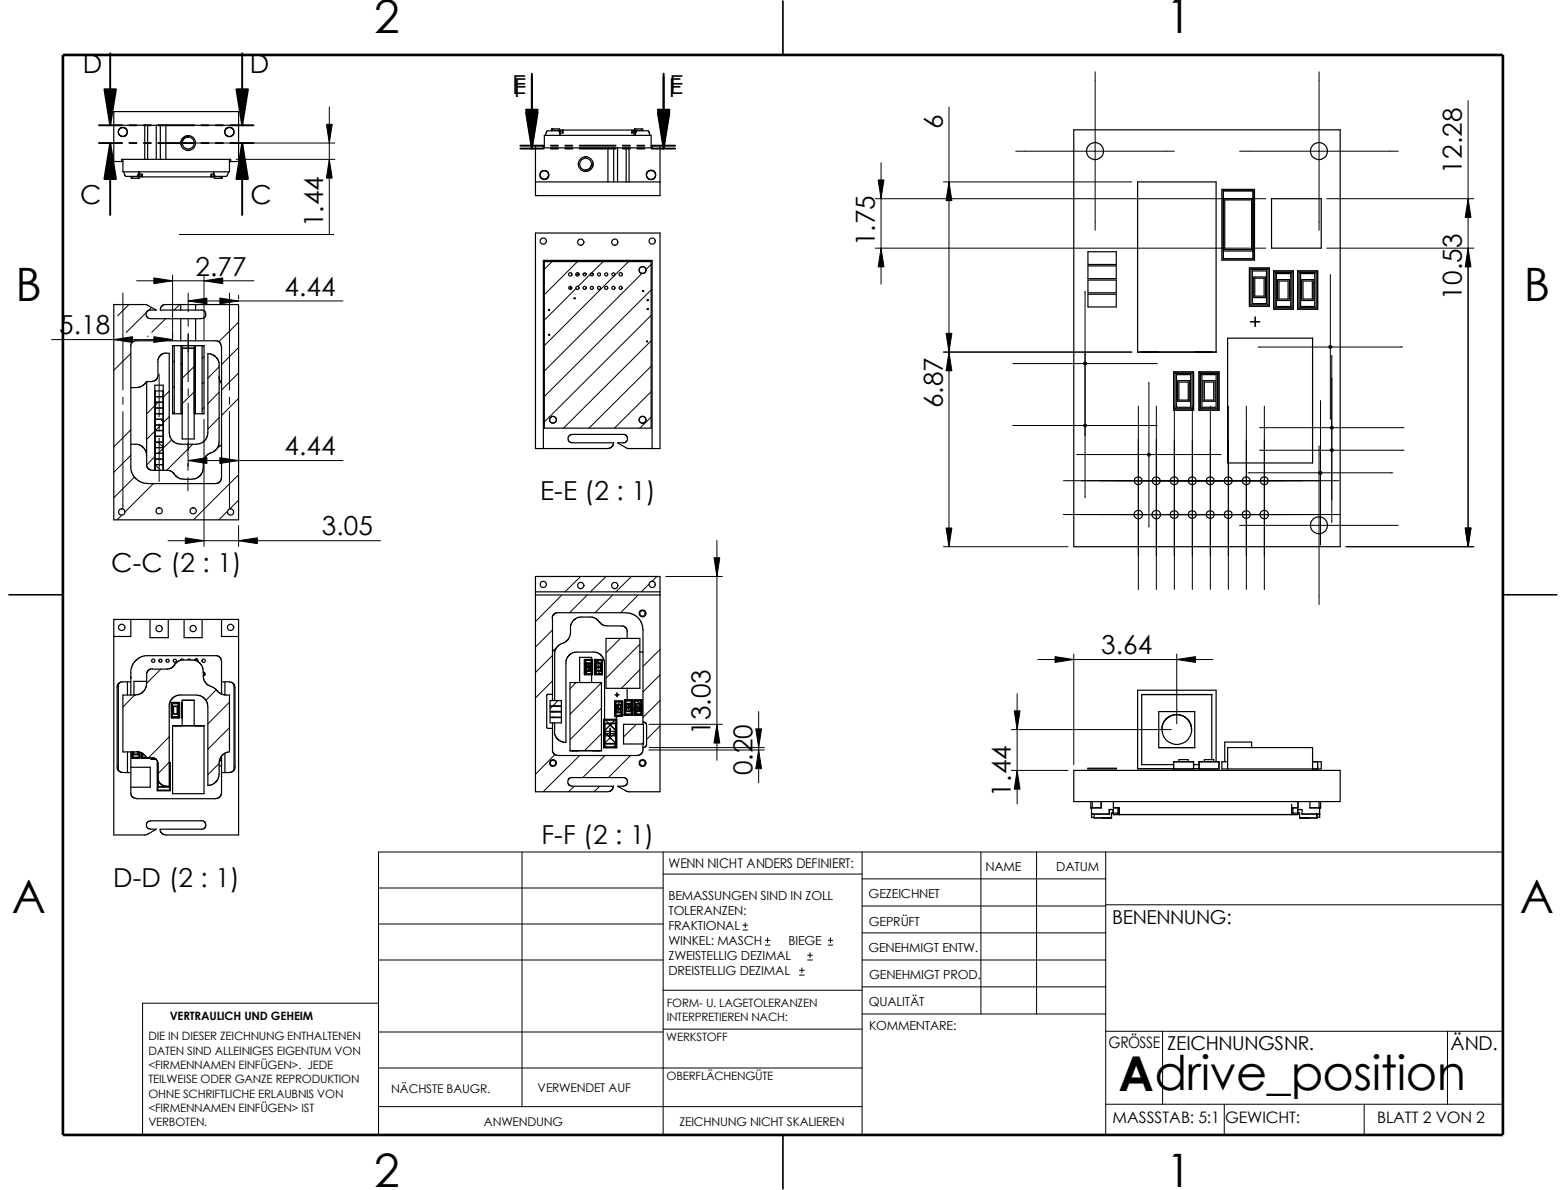
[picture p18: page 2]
KOMMENTARE:

WENN NICHT ANDERS DEFINIERT: | | NAME | DATUM

BEMASSUNGEN SIND IN ZOLL TOLERANZEN: FRAKTIONAL WINKEL: MASCH BIEGE ZWEISTELLIG DEZIMAL DREISTELLIG DEZIMAL | GEZEICHNET

GEPRÜFT | | | BENENNUNG:

GENEHMIGT ENTW.

GENEHMIGT PROD.

FORM- U. LAGETOLERANZEN INTERPRETIEREN NACH: | QUALITÄT

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

WERKSTOFF | | GRÖSSE A drive_position | ZEICHNUNGSNR. | ÄND.

NÄCHSTE BAUGR. | VERWENDET AUF | OBERFLÄCHENGÜTE

ANWENDUNG | ZEICHNUNG NICHT SKALIEREN | | MASSSTAB: 5:1 | GEWICHT: | BLATT 2 VON 2

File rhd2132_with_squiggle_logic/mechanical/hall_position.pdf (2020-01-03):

0.10

3

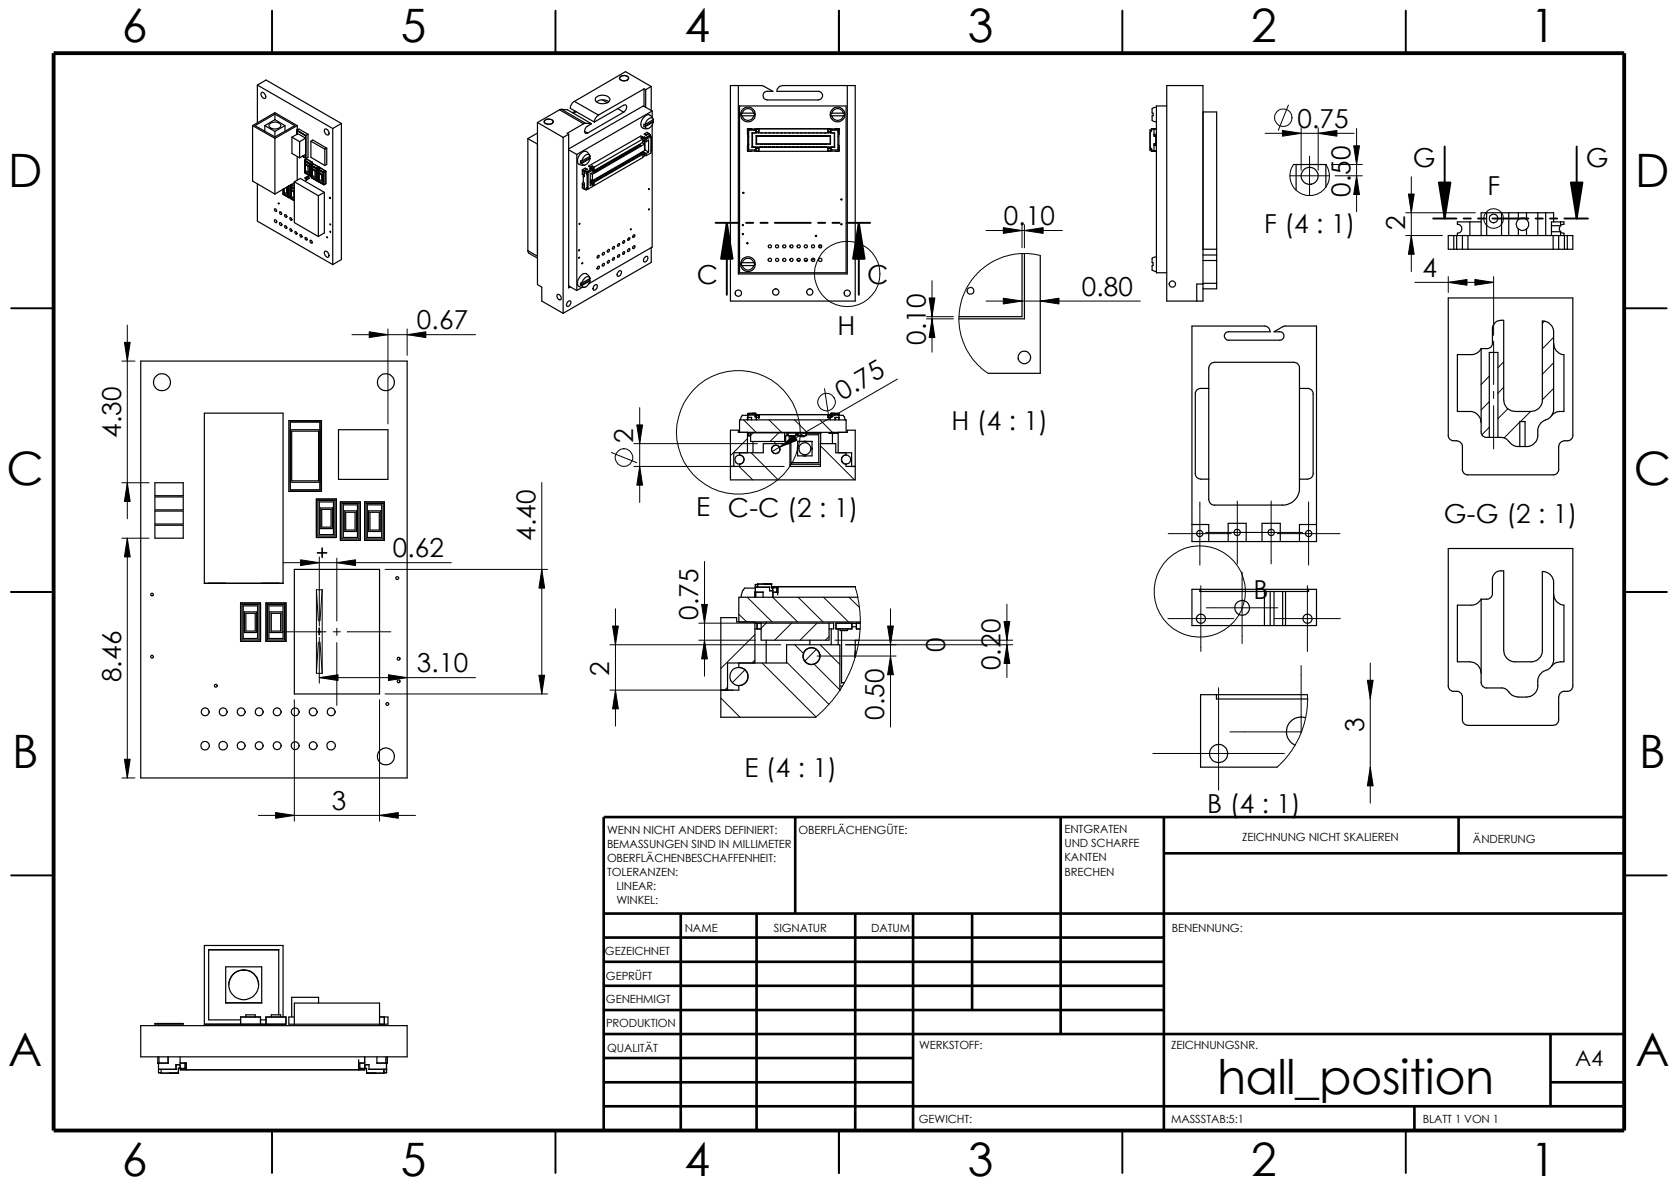
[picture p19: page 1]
OBERFLÄCHENGÜTE:; GEWICHT:; WINKEL:; MASSSTAB:5:1; BLATT 1 VON 1; ÄNDERUNG; BRECHEN; UND SCHARFE KANTEN; ZEICHNUNG NICHT SKALIEREN WENN NICHT ANDERS DEFINIERT:; ENTGRATEN BEMASSUNGEN SIND IN MILLIMETER; OBERFLÄCHENBESCHAFFENHEIT: TOLERANZEN: LINEAR:

NAME | SIGNATUR | DATUM | | | | BENENNUNG:

GEZEICHNET

GEPRÜFT

GENEHMIGT

PRODUKTION

QUALITÄT | | | | WERKSTOFF: | ZEICHNUNGSNR. hall_position | A4
